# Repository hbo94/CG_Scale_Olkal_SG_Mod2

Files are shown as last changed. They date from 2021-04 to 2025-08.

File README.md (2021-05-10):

<p align=center>
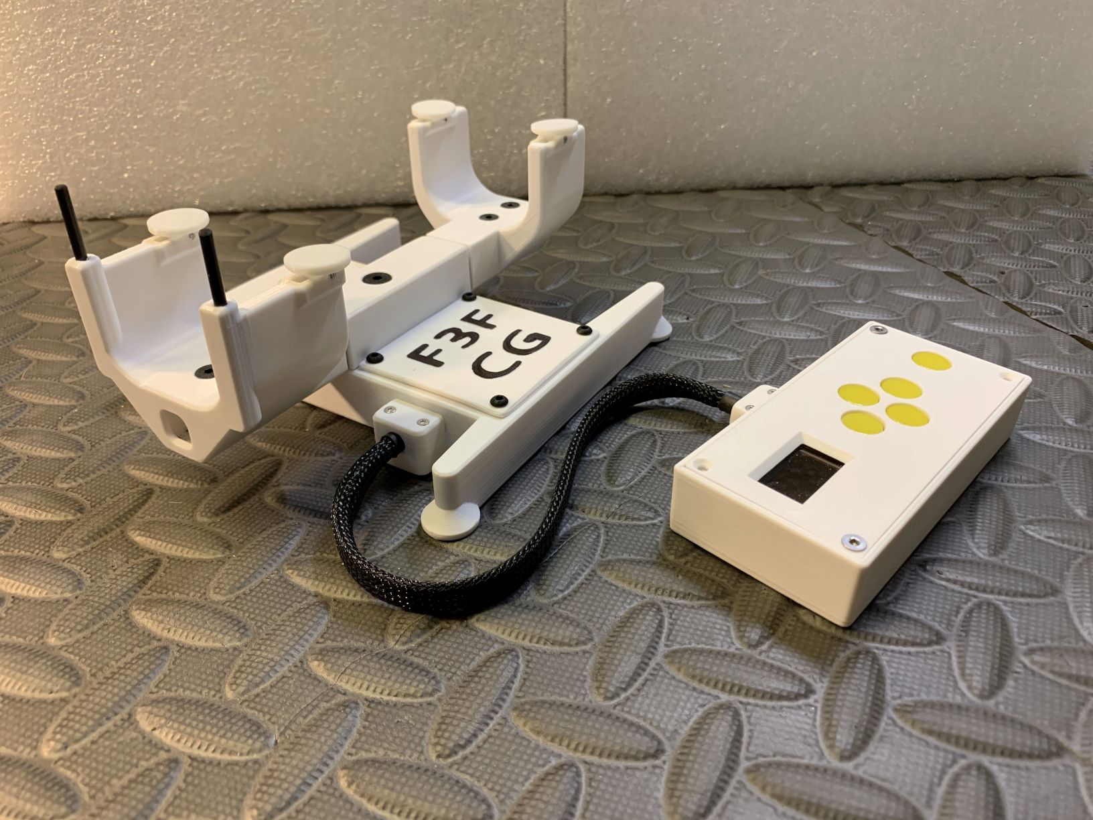
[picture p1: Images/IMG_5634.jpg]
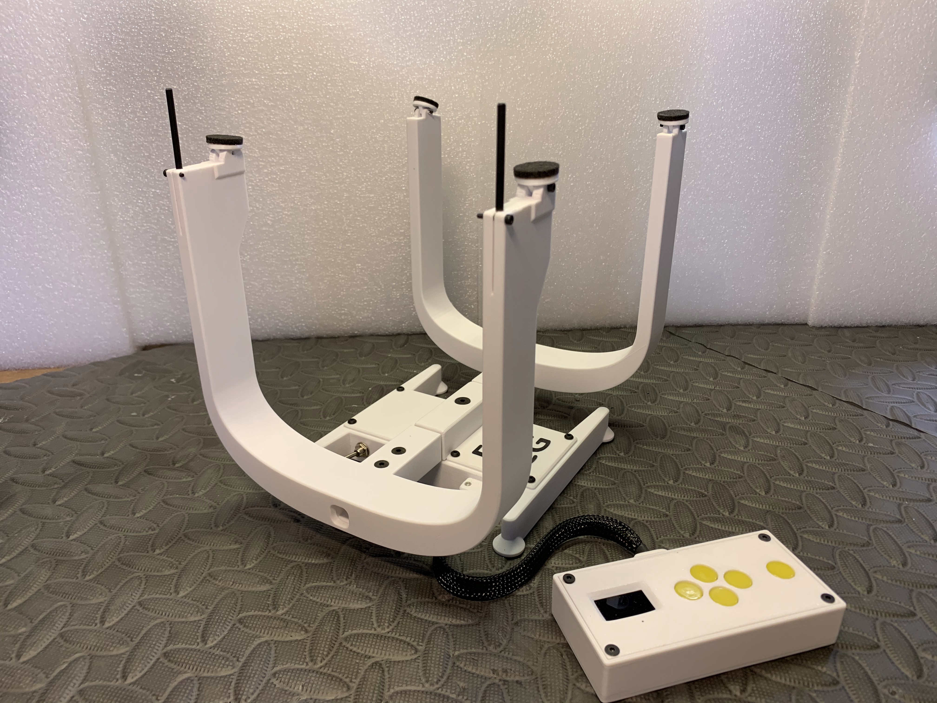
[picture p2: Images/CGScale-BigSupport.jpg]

</p>

## Table of contents
- [Overview](#overview)
- [Dimensions](#dimensions)
- [Change from original project](#change-from-original-project)
  * [For the scale part](#for-the-software-part)
  * [For the software part](#for-the-software-part)
  * [Assembly manual](#assembly-manual)
  * [User manual](#user-manual)
- [Evolution to to](#evolution-to-to)
- [Change Log](#change-log)

## Overview 

A new evolution of the famous Olav Kallhovd CG Scale. For this release, I did a merge of :
* the original project from Olav here: https://github.com/olkal/CG_scale
* the fork from Alain Désandré here: https://github.com/adesandr/CG_Scale_OlkalBreakout
* the fork from Stephan Gamp here: https://github.com/sgamp/CG_Scale_modifiedSG

I didn't change everything, of course, the main part of the original program regarding the scale management is kept, because it works very well and provides very accurate results. I have included a new library, very efficient to capture the key values, from Vedat Ozan Oner (https://www.codeproject.com/Tips/709109/ADKeyboard-Library-for-Arduino).

## Dimensions 
<p align=center>
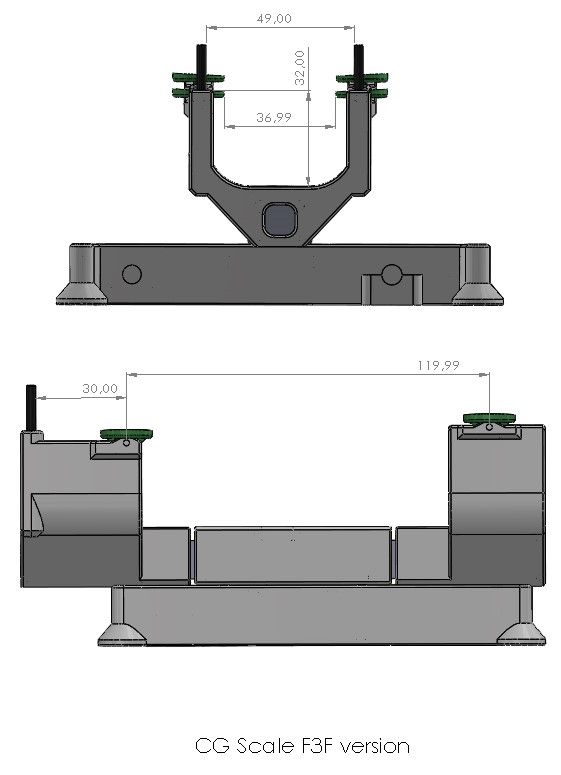
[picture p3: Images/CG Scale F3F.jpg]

</p>
<p align=center>
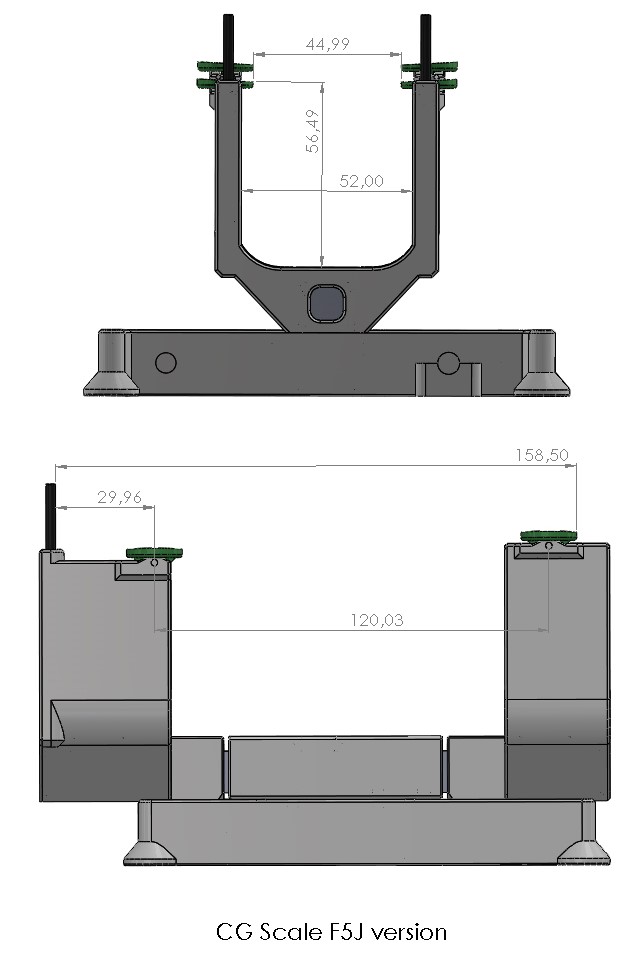
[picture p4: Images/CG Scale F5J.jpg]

</p>
<p align=center>
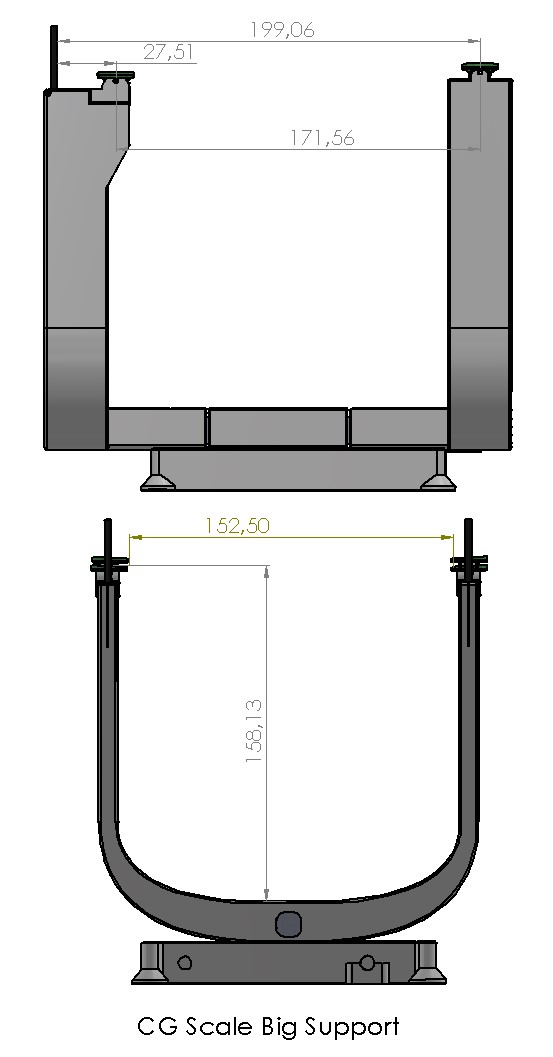
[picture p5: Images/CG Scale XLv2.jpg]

</p>

## Change from original project 

### For the scale part

* a separate box has been designed, in which a keyboard and the OLED display take place.
* the main frame has been optimized to host correctly the 9v battery.
* a wire clamp system has been added, to save the wires with an external control box
* a specific PCB has been designed to reduce the size of the electronic components and have less wires into the scale
* the new design enables the change of the load cell (just need to unweld the old, and weld the new one.

### For the software part

* a interactive menu has been added for the initial configuration
* the autocalibration (a very good idea from Stephen indeed !) has been optimized to win time and accuracy
* it is possible to choose the type of support: little, medium, large 
* the tare configuration menu is simpler and consumes less memory
* two lang are available: English and French
* the keyboard management is done by the excellent library from Vedat, and eliminate the issues when setting the values of key pressed.

### User manual

* User manual in [English](/User_Manual.md)
* Manuel utilisateur en [Français](/Manuel_utilisateur.md)

### Assembly manual

The assembly instructions are perfectly described into the [Alain's project](https://github.com/adesandr/CG_Scale_OlkalBreakout), so I suggest to follow his guide.
You can also find useful instructions into the manual from [Stephen's projet](https://github.com/sgamp/CG_Scale_modifiedSG).

## Evolution to to
* use a bigger display, will be more confortable, such as a 1.3" OLED (very easy to do)
* do a rework of the frame stable enough to accept bigger supports, for bigger models 
* do a help support for tare calibration (mandatory with big supports)
* any other improvement that everyone wants to add !

## Change Log
See the [Change Log file](/ChangeLog.md) to follow the evolutions.

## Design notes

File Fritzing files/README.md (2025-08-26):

The frizing file which add the keyboard. Includes a PCB ready to order (just export in gerber format and upload it to a manufacturer).

CG_Scale_v4 1_bb

For those who cannot use Fritzing (it’s a shame, it’s a really easy and powerful software), I have uploaded the archive coming from the manufacturer website (JLCPCB) : 3469286A_Y1.rar

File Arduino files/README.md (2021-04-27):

This directory contains 2 files :
* MyCGScaleV4.2-Fr.ino
* MyCGScaleV4.2-En.ino

And one library directory : AdKeyboard, to add to your local library Arduino directory.

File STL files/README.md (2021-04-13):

Here are the stl files for the parts that are different from the original release. 

All the other files, from Olav, can be found : https://github.com/olkal/CG_scale/tree/master/STL%20print%20files

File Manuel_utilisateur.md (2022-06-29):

# Manuel utilisateur

## Introduction
Un programme Arduino est structuré en 3 parties :
* les déclarations, inclusions, etc.
* la programme "setup", exécuté une seule fois
* le programme principal, exécuté en boucle.

Le menu permettant de configurer la balance est situé dans l'étape "setup" et n'est donc accessible qu'à la mise sous tension de la balance. Une fois qu'on a quitté le menu, on passe dans le programme principal.

## Le clavier
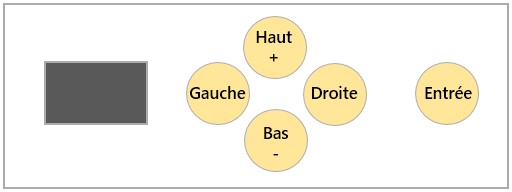
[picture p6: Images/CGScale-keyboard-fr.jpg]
clavier


## Configuration initiale

### Menu principal
Au démarrage de la balance, le menu suivant s'affiche : </br>
**`Configuration`** </br>
` Choix support` </br>
` Calibration` </br>
`>Quitter` </br>

Dans ce premier niveau de menu, la touche `Entrée` permet de sélectionner une action. `Quitter` va lancer le programme principale de la balance.
Dans les sous-menu, la sélection d'une option se fait avec la touche `Droite`, la touche `Gauche` permettant elle de revenir au menu principal.

### Menu Choix support
**`Support : petit `** </br>
` Petit` </br>
` Moyen` </br>
`>Grand` </br>

Ce sous-menu permet de choisir le type de support. Les supports sont montrés en photo sur la page d'accueil du projet. Il est important de choisir le bon support car les caractéristiques sont différentes. Le support configuré dans la mémoire de la balance est affiché lors du démarrage.

### Menu Calibration
**`Calibration`** </br>
`>Config. tare` </br>
` Calib. avant` </br>
` Calib. arriere` </br>

Ce sous-menu permet 3 choses :
* définir le poids de référence de la tare que vous allez utiliser pour calibrer les balances
* calibrer la balance avant
* calibrer la balance arrière </br>

Chaque option est sélectionnée avec la touche `Droite`.

#### Définir le poids de la tare
L'écran affiche alors le dernier poids défini (il est conservé dans la mémoire permanente de la balance). Pour le modifier, on utilise les touches suivantes :
* `Gauche` et `Droite` pour changer la valeur de l'incrément
* `+` et `-` pour augmenter ou diminuer le poids de la valeur de l'incrément
* `Entrée` pendant 5s pour enregistrer le poids dans la mémoire de la balance, et revenir au sous-menu précédent.

#### Calibrer la balance avant
L'opération est très simple :
* poser la tare sur le support avant
* appuyer 5s sur la touche `Entrée` pour démarrer la calibration </br>

L'opération prend quelques secondes, voire une minute, mais pas au-delà. Si ça dure trop longtemps, c'est qu'il y a un problème, et le mieux est de redémarrer la balance.

#### Calibrer la balance arrière
Même opération que pour la balance avant. Seul différence, réussir à faire tenir la tare en équilibre sur les plots, l'exercice peut demander une certaine adresse et causer quelques énervements passagers.
Retour au menu principal avec la touche `Gauche`.

## Utilisation de la balance

Une fois calibrée, la balance fonctionne toute seule, posez un modèle sur les supports, et la lecture du poids et du CG se font en quelques secondes.

**Recommandations pour un bon fonctionnement**
* poser la balance sur une surface stable et plane
* ne pas toucher les supports de la balance pendant sa phase de démarrage
* éviter de peser un modèle lorsqu'il y a du vent, la lecture ne sera pas stable, car le modèle bouge.

## Problèmes rencontrés

### Stabilité des valeurs renvoyées par une balance
* les jauges de contraintes sont livrées avec des fils assez longs, qu'il faut raccourcir au maximum pour diminuer le "bruit", ce "bruit" va empêcher les amplificateurs HX711 de "lire" des valeurs stables et la calibration ne fonctionnera pas.
* pour atténuer encore plus le "bruit", il faut torsader les fils des jauges de contrainte.

### Lors de l'utilisation
* il peut arriver parfois qu'au démarrage, le programme "fige". Je ne sais pas pourquoi, à la compilation, tout est parfait, aucune alerte, la mémoire disponible est amplement suffisante. Je mets ça sur le compte des composants électroniques. Mais ça n'est pas très grave, il suffit de redémarrer la balance, et ça repart.

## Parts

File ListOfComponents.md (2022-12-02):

# List of components 

To build this scale, you need this components :

| Component | Comment | Image | Links |
| --- | --- | :---: | --- |
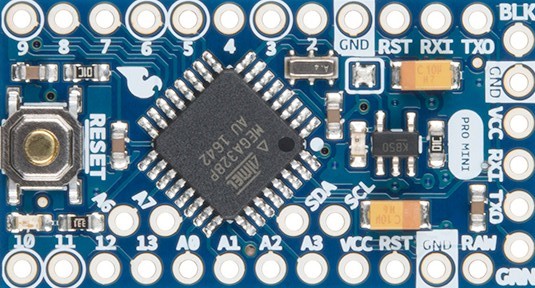
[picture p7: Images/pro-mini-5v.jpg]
pro mini
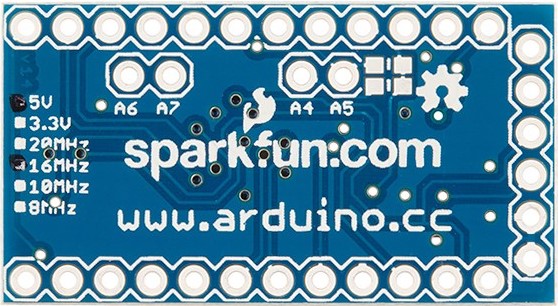
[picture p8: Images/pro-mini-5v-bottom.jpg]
pro mini
| Arduino pro mini 16 mHz 5v | Use this layout of pro mini if you want to use my PCB |    | [Lextronic](https://www.lextronic.fr/pro-mini-5v-16-mhz-dev-11113-3176.html) [Aliexpress](https://fr.aliexpress.com/item/4001333020139.html?spm=a2g0s.9042311.0.0.27426c372ZpzLf) |
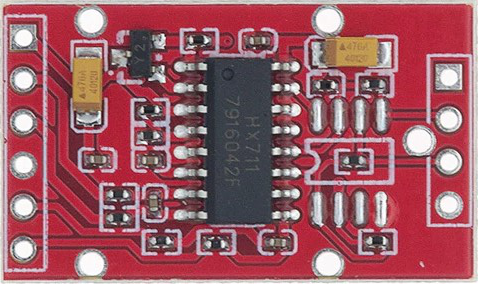
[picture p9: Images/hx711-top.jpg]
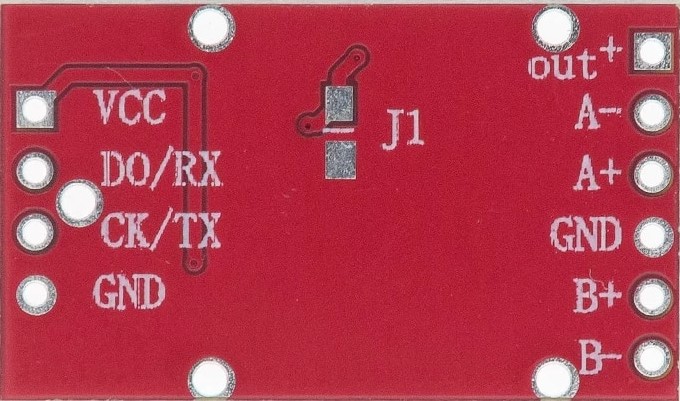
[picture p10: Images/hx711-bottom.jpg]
| HX711 | Only this module with this layout is compatible with my PCB |   | [Aliexpress](https://fr.aliexpress.com/item/1005004774024135.html) [Amazon](https://www.amazon.fr/DollaTek-capteur-Pression-Conversion-m%C3%A9tallique/dp/B081JMSMXV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) |
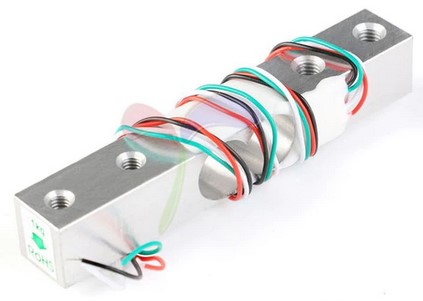
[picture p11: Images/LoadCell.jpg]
LoadCell
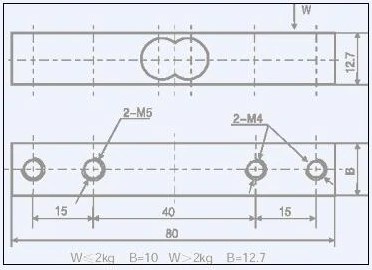
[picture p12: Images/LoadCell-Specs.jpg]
LoadCell
| Load Cell | Beware of cells specs, there are several dimensions |  | [Aliexpress](https://fr.aliexpress.com/item/32763073298.html?spm=a2g0s.9042311.0.0.29fb6c37h6HlYk) |
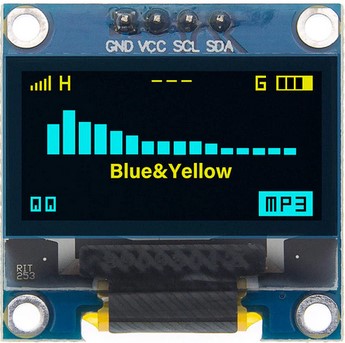
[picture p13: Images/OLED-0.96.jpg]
OLED
| OLED 0.96" display |  |  | [Aliexpress](https://fr.aliexpress.com/item/32643950109.html?spm=a2g0s.9042311.0.0.27426c37AHcnwG) |
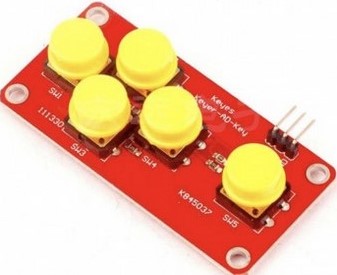
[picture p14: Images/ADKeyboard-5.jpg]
keyboard
| AD Keyboard 5 buttons |  |  | [Hackspark](https://hackspark.fr/fr/interface-homme-machine/2587-ad-keyboard-simulate-5-key-module-analog-button-pour-arduino-sensor-expansion-board.html) [Aliexpress](https://fr.aliexpress.com/item/32961495925.html) |
| Switch 2 positions |  | Switch | [Amazon](https://www.amazon.fr/gp/product/B077D9FRGL/ref=ppx_yo_dt_b_asin_title_o04_s00?ie=UTF8&psc=1) |
| My PCB | Not mandatory, but very usefull  | PCB | Links to order the PCB </br>[JLCPCB](https://jlcpcb.com/)</br>[Aisler](https://aisler.net/) |
| 9V Battery plug | not needed if you want to use a 2S LiPo |  | []() |
| | |  | []() |
| | |  | []() |
| | |  | []() |
| | |  | []() |
| | |  | []() |
| | |  | []() |

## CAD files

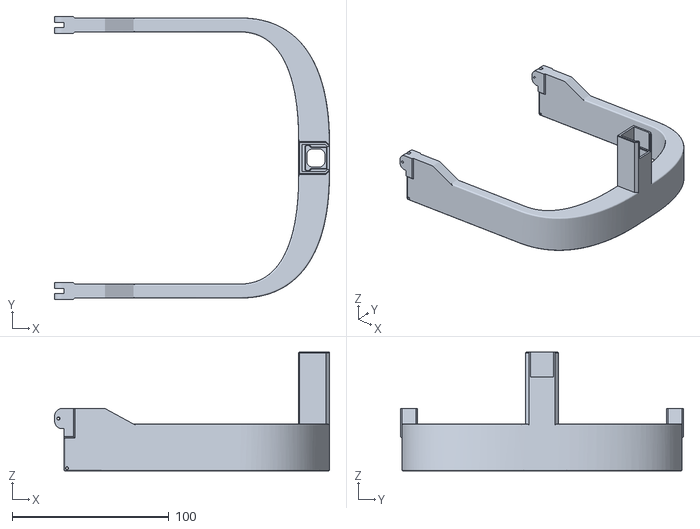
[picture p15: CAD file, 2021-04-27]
STL files/CG Scale Front Support XL.STL
175.7 x 181.0 x 76.0

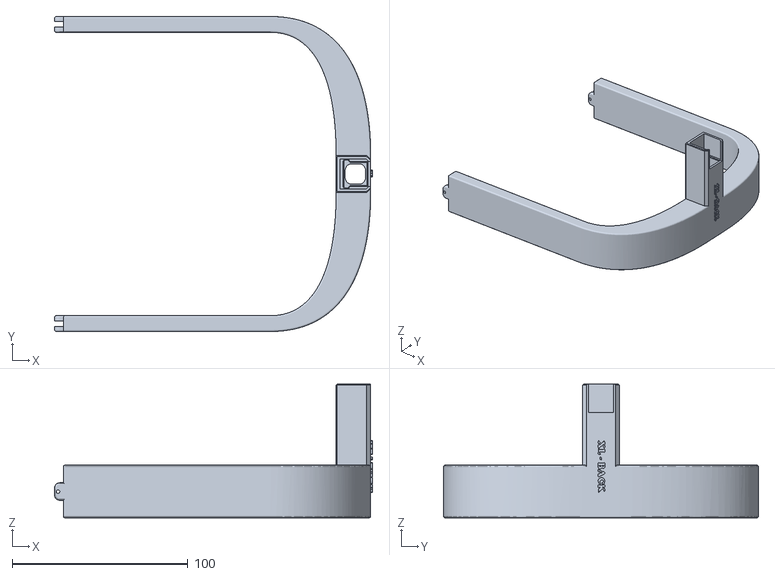
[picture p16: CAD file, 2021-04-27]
STL files/CG Scale Back Support XL.STL
180.7 x 179.0 x 76.0

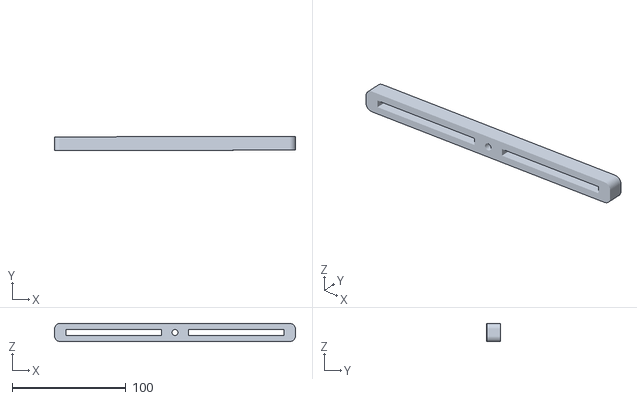
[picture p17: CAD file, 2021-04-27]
STL files/Poutre support tare.STL
212.0 x 12.3 x 16.0

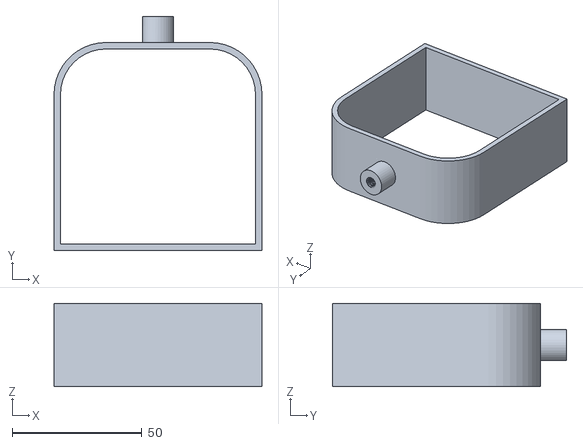
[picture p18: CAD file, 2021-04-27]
STL files/Tare nest.STL
80.0 x 90.0 x 32.0

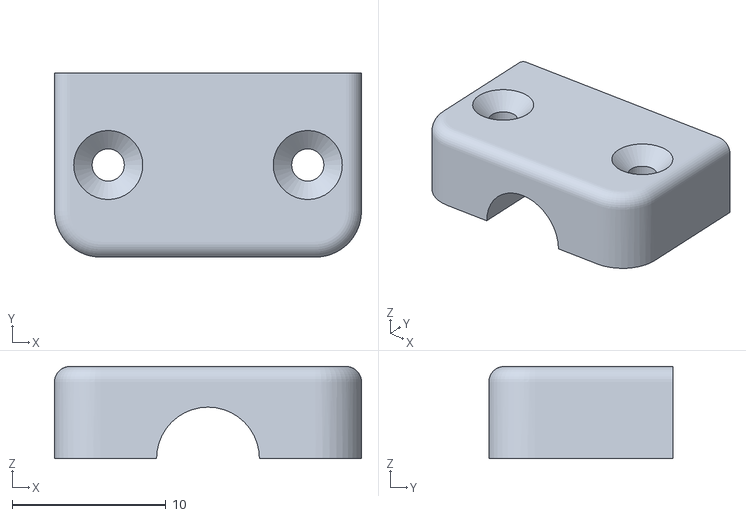
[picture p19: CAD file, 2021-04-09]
STL files/CG Scale wire clamp.STL
20.0 x 12.0 x 6.00

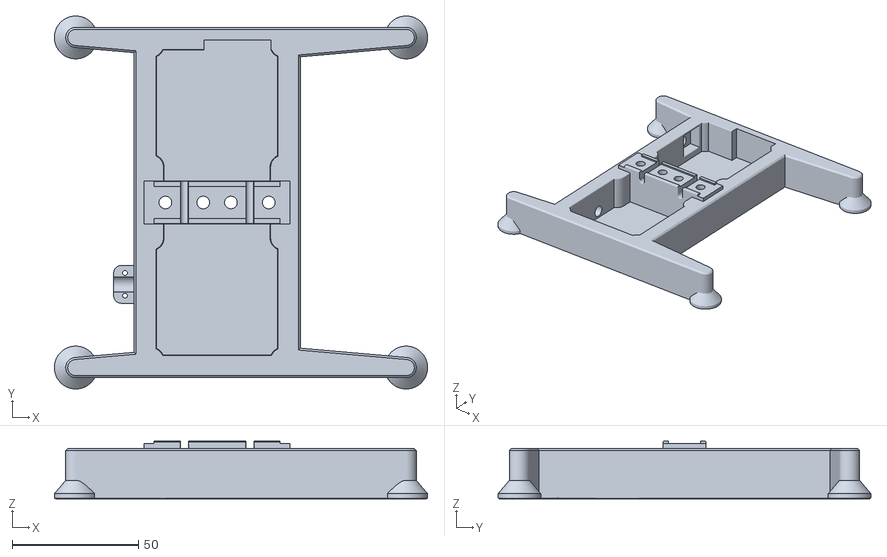
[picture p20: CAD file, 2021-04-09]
STL files/CG_scale_frame.STL
148.0 x 147.9 x 22.8

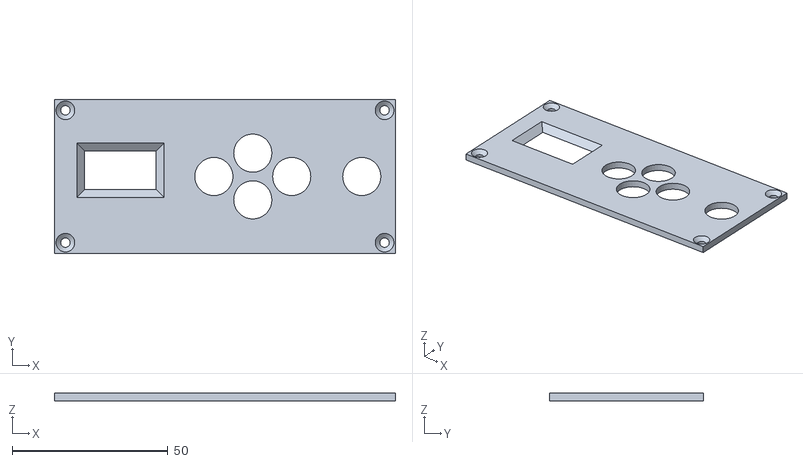
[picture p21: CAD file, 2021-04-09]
STL files/CG Scale cover box.STL
109.5 x 49.5 x 2.50

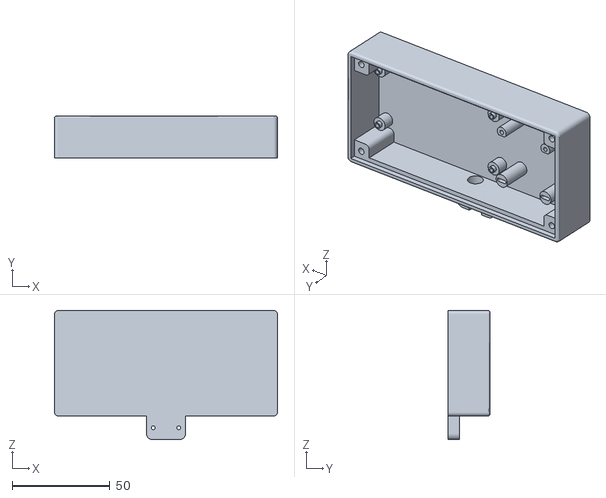
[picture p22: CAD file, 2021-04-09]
STL files/CG Scale display keyboard box .STL
114.0 x 21.5 x 66.0

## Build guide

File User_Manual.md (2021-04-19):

# User manual

## Introduction
An Arduino program is structured in 3 parts:
* declarations, include, etc.
* the "setup" program, executed only once
* the main program, executed in a loop.

The menu for configuring the balance is located in the "setup" step and is therefore only accessible when the balance is powered on. Once you have left the menu, you go to the main program.

## The keyboard
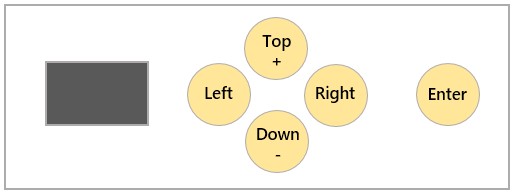
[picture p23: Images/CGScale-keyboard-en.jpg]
keyboard


## Initial setting

### Main Menu
When the scale starts up, the following menu is displayed: </br>
**`Configuration`** </br>
`Support option` </br>
`Calibration` </br>
`> Quit` </br>

In this first menu level, the `Enter` key is used to select an action. `Quit` will launch the balance's main program.
In the sub-menu, the selection of an option is done with the `Right` key, the` Left` key allowing it to return to the main menu.

### Support choice menu
**`Support: small`** </br>
`Small` </br>
`Medium` </br>
`> Large` </br>

This submenu allows you to choose the type of support. For now, the three available supports all have the same characteristics, so there is no need to change the support type. This will be useful in a future version of the software, with larger supports.

### Calibration menu
**`Calibration`** </br>
`> Config. tare` </br>
`Front calibration` </br>
`Back calibration` </br>

This submenu allows 3 things:
* define the reference tare weight that you will use to calibrate the scales
* calibrate the front scale 
* calibrate the back scale </br>

Each option is selected with the `Right` key.

#### Define the tare weight
The screen then displays the last weight defined (it is stored in the permanent memory of the scale). To modify it, the following keys are used:
* `Left` and` Right` to change the value of the increment
* `+` and `-` to increase or decrease the weight of the increment value
* `Enter` for 5s to save the weight in the balance memory, and return to the previous submenu.

#### Calibrate the scale before
The operation is very simple:
* place the tare weight on the front support
* press the `Enter` key for 5s to start the calibration </br>

The operation takes a few seconds or even a minute, but not longer. If it takes too long, there is a problem, and it is best to restart the scale.

#### Calibrate the rear scale
Same operation as for the front scale. The only difference, succeeding in balancing the tare on the blocks, the exercise can require a certain skill and cause some temporary annoyances.
Return to the main menu with the `Left` key.

## Using the scale

Once calibrated, the scale operates on its own, place a model on the supports, and the weight and CG readings are done in seconds.

**Recommendations for proper operation**
* place the scale on a stable and level surface
* do not touch the balance supports during its start-up phase
* Avoid weighing a model when it is windy, the reading will not be stable because the model is moving.

## Problems encountered

### Stability of values returned by a balance
* the strain gauges are delivered with long enough wires, which must be shortened as much as possible to reduce the "noise", this "noise" will prevent the HX711 amplifiers from "reading" stable values and the calibration will not work.
* to attenuate even more the "noise", it is necessary to twist the wires of the strain gauges.

### When using
* It can sometimes happen that at startup, the program "freezes". I don't know why, at compile time, everything is perfect, no alerts, the available memory is more than sufficient. I put it down to electronic components. But that's not a big deal, just restart the scale, and it starts again.

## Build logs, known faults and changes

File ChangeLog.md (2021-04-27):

## 2021-04-27
- add a new big support really bigger to enlarge the scope of usage : <p align=center>

</p>
- change the big support configuration for the new one 
- tested with 2 gauges (3kg and 5kg) to accept 7-8 kg models.
- Software version : 4.2

## 2021-04-08
- Initial build
- Software version : 4.1

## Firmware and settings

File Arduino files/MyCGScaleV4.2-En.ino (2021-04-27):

// Size of EEPROM
#define EESIZE 1024

#define TRUE 1
#define FALSE 0

//Include the graphics library.
#include "U8glib.h"
#include <AdKeyboard.h>
#include <HX711_ADC.h>
#include <EEPROM.h>
#include <Wire.h>

// pin for keyboard
AdKeyboard adKeyboard(6);

//HX711 constructor (dout pin, sck pin)
HX711_ADC ScaleFront(A2, A3); //HX711 pins front sensor (DOUT, PD_SCK)
HX711_ADC ScaleBack(A0, A1); //HX711 pins rear sensor (DOUT, PD_SCK)

//Initialize display.
U8GLIB_SSD1306_128X64 u8g(U8G_I2C_OPT_NONE | U8G_I2C_OPT_DEV_0);

//define values for scale
float SW_front = 10.0; //ScaleWeight
float SW_back = 10.0;
float SF_front = 3000.00; //ScaleFactor
float SF_back = 3000.00;
float SF_front_default = 3000.00;
float SF_back_default = 3000.00;
byte calibFrontOK;
byte calibBackOK;

// wings support
int DistSupPins;
int DistStopSup;
int CGoffset;
byte supportSelected;


//values for display with U8g font with helvR10 (11 pixels high font) , we have 64 pixels high
byte abst = 17 ;//number of pixels between the lines, including the interligne space (4 pixels)
byte line1 = 11;
byte line2 = line1 + 1 * abst ;
byte line3 = line1 + 2 * abst ;
byte line4 = line1 + 3 * abst ;

// declaration of the subroutine
void toOLED(const char* row1, const char* row2, const char* row3, const char* row4); //output to OLED using u8g lib
void displayMenu(byte numMenu, byte selectedItem); // to display the setup menu
int readBattVoltage(boolean *bWarn); //check batt value
int scaleFactorSupport (int supportSelected); // return CGoffset regarding the support selected


// menu configuration
byte selectedItem = 3; // default value = Exit menu
byte numMenu; // menu number
byte setupIsFinish = 0;

//define values for eeprom
byte adrSF_front = 0;  //adresses for EEPROM values
byte adrSF_back = 5;
byte adrTotalWeight = 10;
byte adrcalibFrontOK = 15;
byte adrcalibBackOK = 20;
byte adrSupportSelected = 25;

//various stuff
int batRefPin = A7;// pin to check BAT value
boolean bBatWarning = FALSE;
byte loc = 0;

// tare weight definition
word weight;
word incr = 1;
char str_weight[6] = "";
char str_incr[6] = {"1g"};

void setup(void)
{
  byte ScaleFront_rdy = 0;
  byte ScaleBack_rdy = 0;
  int stabilisingtime = 3000;

  //Serial.begin(9600);
  u8g.setFont(u8g_font_helvR10);

  // Reading the eeprom to get stored values
  EEPROM.get(adrTotalWeight, weight); // reference weight for calibration
  EEPROM.get(adrSupportSelected, supportSelected); // type of support selected
  EEPROM.get(adrcalibFrontOK, calibFrontOK);
  EEPROM.get(adrcalibBackOK, calibBackOK);
  if (calibFrontOK != 0) {
    EEPROM.get(adrSF_front, SF_front); // scale factor for Front
  };
  if (calibBackOK != 0) {
    EEPROM.get(adrSF_back, SF_back);   // scale factor for Back
  };
  //Serial.println((String)"L89  ref. weight=" + weight + "   supportSelected=" + supportSelected + "   calibFrontOK=" + calibFrontOK + "   calibBackOK=" + calibBackOK + "   SF_front=" + SF_front + "  SF_back=" + SF_back + "  CGoffset=" + CGoffset);

  // subroutine to listen the keyboard
  adKeyboard.setClickCallback(clickHandler);
  adKeyboard.setPressCallback(pressHandler);

  // starting the scales
  toOLED("CG SCALE", "", "Initialization", "in progress ...");
  ScaleFront.begin(); //start the Scales
  ScaleBack.begin();
  ScaleFront.start(2000); //Stabilize Scales
  ScaleBack.start(2000);

  while ((ScaleFront_rdy + ScaleBack_rdy) < 2) { //run startup, stabilisation and tare, both modules simultaneously
    if (!ScaleFront_rdy) ScaleFront_rdy = ScaleFront.startMultiple(stabilisingtime);
    if (!ScaleBack_rdy) ScaleBack_rdy = ScaleBack.startMultiple(stabilisingtime);
  }

  numMenu = 1;

  // menu loop
  while (setupIsFinish != 1) {
    adKeyboard.update();
    //Serial.println((String)"numMenu=" + numMenu);
    switch (numMenu) {
      case 0: // main loop, scale running
        CGoffset = scaleFactorSupport(supportSelected);  // run once setup is finish
        setupIsFinish = 1;
        break;

      case 1: // main menu
        displayMenu(numMenu, selectedItem);
        break;

      case 2: // support menu
        displayMenu(numMenu, selectedItem);
        break;

      case 3: // calibration menu
        displayMenu(numMenu, selectedItem);
        break;

      case 4: // tare definition menu
        toOLED("Tare value:", str_weight, "increment:", str_incr);
        break;

      case 5:
        break;

      case 6:
        break;
    } // end of switch
  } // end of while

  // finishing setting the scales
  ScaleFront.setCalFactor(SF_front); // set calibration factor
  ScaleBack.setCalFactor(SF_back); // set calibration factor
  ScaleFront.tareNoDelay();  //Calibweight has to be removed beforehand
  ScaleBack.tareNoDelay();
  toOLED("End of", "configuration", "Ready to weight", "a model.");
  delay(2000);


} // end of setup loop

void loop(void) {
  float CGratio;
  long int CG;
  long int weightTot;
  int printInterval = 500; // LCD/Serial refresh interval
  char weightLCD[17] = "displ";
  char CGtoLCD[17] = "displ";
  char batToLCD[17] = "";
  int t1;
  // u8g.setFont(u8g_font_unifont);

  ScaleFront.update();
  ScaleBack.update();

  if (t1 < millis()) {  //start calculation
    t1 = millis() + printInterval;
    SW_front = ScaleFront.getData();
    SW_back = ScaleBack.getData();

    weightTot = (SW_back + SW_front) * 100;

    if (SW_front > 5 && SW_back > 5) {
      SW_front = SW_front / 10;
      SW_back = SW_back / 10;
      CGratio = (((SW_back * 10000) / (SW_front + SW_back)));
      CG = ((((DistSupPins) * CGratio) / 1000) - ((DistSupPins * 10) / 2) + CGoffset);
    }
    else
      CG = 0;

    if (weightTot < 0 && weightTot >= -100)
      weightTot = 0;

    if (weightTot < -100)
      sprintf(weightLCD, "Error");
    else
      sprintf (weightLCD, "Weight: %ld g", weightTot / 100);

    if (CG != 0)
      sprintf(CGtoLCD, "CG: %ld mm", CG / 100);
    else
      sprintf(CGtoLCD, "No CG");

    // Battery value display
    int batVal = readBattVoltage(&bBatWarning);
    if (bBatWarning)
      sprintf(batToLCD, "Bat low: %d.%d V", (batVal / 1000), ((batVal % 1000) / 100), ((batVal % 100) / 10));
    else
      sprintf(batToLCD, "Bat ok: %d.%d V", (batVal / 1000), ((batVal % 1000) / 100), ((batVal % 100) / 10));

    //BatVal, Weight and Cg OLED display
    //Serial.println((String)"Bat: " + bat + " Weight: " + weightTot + " CG: " + CG);
    toOLED(batToLCD, "", weightLCD, CGtoLCD);

  } //end if...t1 millis
}


void clickHandler(int key) {

  if (key == 0 && numMenu != 4) {
    numMenu = 1;
  };

  // Main menu
  if (numMenu == 0) {
    switch (key) {
      case 0: // Left
        //Serial.println((String)"210: menu = " + numMenu + "   selectedItem = " + selectedItem);
        numMenu = 1;
        // selectedItem=1;
        // displayMenu(numMenu, selectedItem);
        break;
    };
  };

  if (numMenu == 1) {
    //Serial.println((String)"222: menu = " + numMenu + "   selectedItem = " + selectedItem);
    switch (key) {

      case 0: // Left
        // nothing to do
        break;

      case 1: // Up
        if (selectedItem > 1) {
          selectedItem = selectedItem - 1;
          //Serial.println((String)"149: menu = " + numMenu + "   selectedItem = " + selectedItem);
        };
        break;

      case 2: // Down
        if (selectedItem < 3) {
          selectedItem = selectedItem + 1;
          //Serial.println((String)"155: menu = " + numMenu + "   selectedItem = " + selectedItem);
        };
        break;

      case 3: // Right
        break;

      case 4: // Enter
        if (selectedItem == 1) { // menu support selected
          numMenu = 2;
          //Serial.println((String)"201: Going to the support menu");
        };
        if (selectedItem == 2) { // menu calibration selected
          numMenu = 3;
          //Serial.println((String)"205: Going to the calibration menu");
        };
        if (selectedItem == 3) { // quit the menu
          numMenu = 0;
          // setupIsFinish = 1;
          //Serial.println((String)"271: going to the main loop");
        };
    };
  };

  // support menu
  if (numMenu == 2) {
    //Serial.println((String)"264: menu = " + numMenu + "   selectedItem = " + selectedItem);
    switch (key) {

      case 0: // Left
        // nothing to do
        break;

      case 1: // Up
        if (selectedItem > 1) {
          selectedItem = selectedItem - 1;
          //Serial.println((String)"187: menu = " + numMenu + "   selectedItem = " + selectedItem);
        };
        break;

      case 2: // Down
        if (selectedItem < 3) {
          selectedItem = selectedItem + 1;
          //Serial.println((String)"193: menu = " + numMenu + "   selectedItem = " + selectedItem);
        };
        break;

      case 3: // Right
        // nothing to do
        break;

      case 4: // Enter
        if (selectedItem == 1) { // support 'petit' selected
          //Serial.println("201: Support selected : petit");
          supportSelected = 1;
        };
        if (selectedItem == 2) { // support 'moyen' selected
          //Serial.println("206: Support selected : moyen");
          supportSelected = 2;
        };
        if (selectedItem == 3) { // support 'grand' selected
          //Serial.println("211: Support selected : grand");
          supportSelected = 3;
        };
        EEPROM.put(adrSupportSelected, supportSelected);
        CGoffset = scaleFactorSupport(supportSelected);
    }
  };

  // Calibration menu
  // Serial.println((String)"menu = " + numMenu + "   selectedItem = " + selectedItem);
  if (numMenu == 3) {
    switch (key) {

      case 0: // Left
        // quit the calibration menu
        numMenu = 1;
        break;

      case 1: // Up
        if (selectedItem > 1) {
          selectedItem = selectedItem - 1;
          //Serial.println((String)"menu = " + numMenu + "   selectedItem = " + selectedItem);
        };
        break;

      case 2: // Down
        if (selectedItem < 3) {
          selectedItem = selectedItem + 1;
          //Serial.println((String)"menu = " + numMenu + "   selectedItem = " + selectedItem);
        };
        break;

      case 3: // Right
        if (selectedItem == 1) { // Tare configuration procedure
          //Serial.println((String)"Going to the tare configuration procedure");
          sprintf(str_weight, "%d%s", weight, "g");
          numMenu = 4;
        };
        if (selectedItem == 2) { // Front calibration procedure
          toOLED("Put the tare on", "the front scale", "Press 'Enter' 5s", "to start.");
          numMenu = 5;
        };
        if (selectedItem == 3) { // Back calibration procedure
          toOLED("Put the tare on", "the back scale", "Press 'Enter' 5s", "to start.");
          numMenu = 6;
        };
        break;

      case 4: // Enter
        // nothing to do for now
        break;
    }
  };

  if (numMenu == 4) {     // Tare weight definition menu
    //Serial.println((String)"253: weight=" + str_weight + "  incr=" + str_incr);
    switch (key) {

      case 0 : // Left
        // decrease increment
        switch (incr) {
          case 1:
            // nothing to do, already at the minimum
            break;
          case 10:
            incr = 1;
            sprintf(str_incr, "%d%s", incr, "g");
            break;
          case 100:
            incr = 10;
            sprintf(str_incr, "%d%s", incr, "g");
            break;
          case 1000:
            incr = 100;
            sprintf(str_incr, "%d%s", incr, "g");
            break;
            //Serial.println((String)"273: weight=" + str_weight + "  incr=" + str_incr);
        }
        break;

      case 1: // Up
        weight = weight + incr;
        sprintf(str_incr, "%d%s", incr, "g");
        sprintf(str_weight, "%d%s", weight, "g");
        //Serial.println((String)"337: weight=" + str_weight + "  incr=" + str_incr);
        break;

      case 2: // Down
        weight = weight - incr;
        sprintf(str_incr, "%d%s", incr, "g");
        sprintf(str_weight, "%d%s", weight, "g");
        //Serial.println((String)"343: weight=" + str_weight + "  incr=" + str_incr);
        break;

      case 3 : // Right
        // increase increment
        switch (incr) {
          case 1:
            incr = 10;
            sprintf(str_incr, "%d%s", incr, "g");
            break;
          case 10:
            incr = 100;
            sprintf(str_incr, "%d%s", incr, "g");
            break;
          case 100:
            incr = 1000;
            sprintf(str_incr, "%d%s", incr, "g");
            break;
          case 1000:
            // nothing to do, already at the maximum
            break;
            //Serial.println((String)"301: weight=" + str_weight + "  incr=" + str_incr);
        }
        break;

      case 4: // Enter
        break;
    } // end switch key

  } // end of if numMenu=4

} // end of clickHandler subroutine


void pressHandler(int key) {

  if (numMenu == 4 && key == 4) {
    toOLED("New weight", "of the tare", str_weight, "");
    EEPROM.put(adrTotalWeight, weight);
    delay(4000);
    numMenu = 3;
    selectedItem = 2;
  }

  if (numMenu == 5) {   // menu 5 => front scale calibration procedure

    switch (key) {
      case 0: // Left
        break;
      case 1: // Up
        break;
      case 2: // Down
        break;
      case 3: // Right
        break;
      case 4: // Enter
        int i = 0;
        ScaleFront.setCalFactor(SF_front_default); //set default to be faster
        ScaleFront.update();
        delay(200);
        SW_front = ScaleFront.getData();
        //Serial.println((String)"403: SW_front=" + SW_front);
        SF_front = ScaleFront.getCalFactor();
        //Serial.println((String)"405: SF_front=" + SF_front);
        int itr = 10;
        word diff;

        while (abs(SW_front - weight) >= 0.25) {
          ScaleFront.update();
          delay(200);
          diff = abs(SW_front - weight);
          if (i == 0) { //just to see on display that programm is not hanging
            toOLED("Front scale", "", "calibration", "in progress   |");
            toOLED("Front scale", "", "calibration", "in progress   /");
            i = 1;
          }
          else {
            i = 0;
            toOLED("Front scale", "", "calibration", "in progress   -");
            toOLED("Front scale", "", "calibration", "in progress   \\");
          }// ende else (i==0)

          if (diff >= 1000) {
            itr = 500;
          }
          if (diff >= 100 && diff < 1000 ) {
            itr = 100;
          }
          if (diff >= 50 && diff < 100 ) {
            itr = 25;
          }
          if (diff >= 7 && diff < 50) {
            itr = 5;
          }
          if (diff < 7 ) {
            itr = 1;
          }

          // Serial.println((String)"diff=" + diff + "  itr=" + itr + "  SW_front=" + SW_front + "  factor=" + SF_front);

          if (SW_front < weight) { //start autocalib
            //diff = abs(SW_front - weight);
            SF_front = SF_front - itr;
            ScaleFront.setCalFactor(SF_front);
          }
          if (SW_front > weight) {
            SF_front = SF_front + itr;
            ScaleFront.setCalFactor(SF_front);
          }
          SW_front = ScaleFront.getData();
        } // end while

        if (SF_front != SF_front_default) {
          // Serial.println((String)"460: we have values SF_front=" + SF_front + "   SW_front=" + SW_front);
          EEPROM.put(adrSF_front, SF_front);  //write calibrated value to EEPROM
          toOLED("Front scale", "calibration", "finished.", "");
          calibFrontOK = 1;
          EEPROM.put(adrcalibFrontOK, calibFrontOK);
          delay(2000);
        };

        break;
    } // end switch key

    numMenu = 3;
    selectedItem = 3;

  }// end menu 5


  if (numMenu == 6) {   // menu 6 => back scale calibration procedure

    switch (key) {
      case 0: // Left
        break;
      case 1: // Up
        break;
      case 2: // Down
        break;
      case 3: // Right
        break;
      case 4: // Enter
        int i = 0;
        ScaleBack.setCalFactor(SF_back_default); //set default to be faster
        ScaleBack.update();
        delay(200);
        SW_back = ScaleBack.getData();
        SF_back = ScaleBack.getCalFactor();
        int itr = 10;
        word diff;

        while (abs(SW_back - weight) >= 0.25) {
          ScaleBack.update();
          delay(200);
          diff = abs(SW_back - weight);
          if (i == 0) { //just to see on display that programm is not hanging
            toOLED("Back scale", "", "calibration", "in progress   |");
            toOLED("Back scale", "", "calibration", "in progress   /");
            i = 1;
          }
          else {
            i = 0;
            toOLED("Back scale", "", "calibration", "in progress   -");
            toOLED("Back scale", "", "calibration", "in progress   \\");
          }// ende else (i==0)

          if (diff >= 1000) {
            itr = 500;
          }
          if (diff >= 100 && diff < 1000 ) {
            itr = 100;
          }
          if (diff >= 50 && diff < 100 ) {
            itr = 25;
          }
          if (diff >= 7 && diff < 50) {
            itr = 5;
          }
          if (diff < 7 ) {
            itr = 1;
          }
          //Serial.println((String)"diff=" + diff + "  itr=" + itr + "  SW_back=" + SW_back + "  factor=" + SF_back);

          if (SW_back < weight) { //start autocalib
            SF_back = SF_back - itr;
            ScaleBack.setCalFactor(SF_back);
          }
          if (SW_back > weight) {
            SF_back = SF_back + itr;
            ScaleBack.setCalFactor(SF_back);
          }
          SW_back = ScaleBack.getData();
        }// end while

        if (SF_back != SF_back_default) {
          EEPROM.put(adrSF_back, SF_back);  //write calibrated value to EEPROM
          toOLED("Back scale", "calibration", "finished.", "");
          calibBackOK = 1;
          EEPROM.put(adrcalibBackOK, calibBackOK);
          delay(2000);
        };
        break;
    } // end switch key

    numMenu = 1;
    selectedItem = 3; // ready to quit the main menu

  } // end menu 6

}


void displayMenu(byte num, byte selectedItem) {
  char const *menuItem10 = "Configuration";
  char const *menuItem20 = " Support option";
  char const *menuItem30 = " Calibration";
  char const *menuItem21 = "Support : ";
  char const *menuItem22 = " Small";
  char const *menuItem23 = " Medium";
  char const *menuItem24 = " Large";
  char const *menuItem31 = " Tare config.";
  char const *menuItem32 = " Front calibration";
  char const *menuItem33 = " Back calibration";
  char const *menuItem40 = " Quit";
  char selected[20] = {""};
  char support[20] = {""};
  char selector[] = {'>'};
  char r1[22] ;
  char r2[22] ;
  char r3[22] ;
  char r4[22] ;
  if (supportSelected == 1) {
    strcpy(support, menuItem21);
    strcat(support, "small");
  }
  if (supportSelected == 2) {
    strcpy(support, menuItem21);
    strcat(support, "medium");
  }
  if (supportSelected == 3) {
    strcpy(support, menuItem21);
    strcat(support, "large");
  }

  switch (num) {

    case 1: // main menu
      //r1 = menuItem10;
      //r2 = menuItem20;
      //r3 = menuItem30;
      //r4 = menuItem40;
      strcpy(r1, menuItem10);
      strcpy(r2, menuItem20);
      strcpy(r3, menuItem30);
      strcpy(r4, menuItem40);
      break;

    case 2: // support menu
      //r1 = support;
      //r2 = menuItem22;
      //r3 = menuItem23;
      //r4 = menuItem24;
      strcpy(r1, support);
      strcpy(r2, menuItem22);
      strcpy(r3, menuItem23);
      strcpy(r4, menuItem24);
      break;

    case 3: // calibration menu
      //r1 = menuItem30;
      //r2 = menuItem31;
      //r3 = menuItem32;
      //r4 = menuItem33;
      strcpy(r1, menuItem30);
      strcpy(r2, menuItem31);
      strcpy(r3, menuItem32);
      strcpy(r4, menuItem33);
      break;
  }
  switch (selectedItem) {
    case 1:
      strcpy(selected, r2);
      selected[0] = '>';
      toOLED(r1, selected , r3, r4);
      break;
    case 2:
      strcpy(selected, r3);
      selected[0] = '>';
      toOLED(r1, r2 , selected, r4);
      break;
    case 3:
      strcpy(selected, r4);
      selected[0] = '>';
      toOLED(r1, r2 , r3, selected);
      break;
  }
} // end void displayMenu

void toOLED(const char* row1, const char* row2, const char* row3, const char* row4) {
  u8g.firstPage();
  do {
    u8g.drawStr(0, line1, row1);
    u8g.drawStr(0, line2, row2);
    u8g.drawStr(0, line3, row3);
    u8g.drawStr(0, line4, row4);
  } while (u8g.nextPage());
}//end void toOLED

int readBattVoltage(boolean * bWarn) { // read battery voltage
  long battvalue = 0;
  /*--- Double read to increase the stability ---*/
  battvalue += analogRead(batRefPin);
  battvalue += analogRead(batRefPin);
  /*--- Simple cross product and bride resistor divider value * 2 because we have done two analog read ---*/
  battvalue *= 4883L; // analog reading * (5.00V*1000000)/1024 (adjust value if VCC is not 5.0V)
  battvalue /= 640L; // this number comes from the resistor divider value ((R2/(R1+R2))*1000)/noof analogreadings (adjust value if required)
  /*--- Warning if battvalue < 5,5 V. Old Value 7,5 V ----*/
  if (battvalue < 5500) {
    *bWarn = TRUE;
  }

  return battvalue;
}
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

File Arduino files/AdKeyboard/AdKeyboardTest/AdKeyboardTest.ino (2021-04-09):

/*
Ozan Oner
Library test for http://www.cooking-hacks.com/adkeyboard-module

Connections (ADKeyboard-Arduino)
VCC-5v
GND-GND
S-A0
*/

#include <Arduino.h>
#include <AdKeyboard.h>

AdKeyboard adKeyboard(0);

void setup() {
  Serial.begin(9600);
  adKeyboard.setClickCallback(clickHandler);  
  adKeyboard.setPressCallback(pressHandler);  
  adKeyboard.setTwoPressCallback(twoPressHandler);  
}

void loop() {
  adKeyboard.update();
}

void clickHandler(int key) {
  Serial.print("clickHandler: ");
  Serial.println(key);
}

void pressHandler(int key) {
  Serial.print("pressHandler: ");
  Serial.println(key);
}

void twoPressHandler(int k1, int k2) {
  Serial.print("twoPressHandler: ");
  Serial.print(k1);
  Serial.print(" ");
  Serial.println(k2);
}
